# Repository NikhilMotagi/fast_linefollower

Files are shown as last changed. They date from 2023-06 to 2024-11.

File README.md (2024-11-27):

# fast_linefollower
This autonomous robot is designed to accurately follow a defined black line on a white surface. It utilizes an Arduino Nano microcontroller as its brain, processing sensor data and controlling the robot's movement.

**Key Components:**

- **Microcontroller:** Arduino Nano
- **Sensors:** 8-Array IR Sensor
- **Motor Driver:** TB6612FNG
- **Motors:** N20 12V DC Motors
- **Power Supply:** 12V Battery with LM7805 Voltage Regulator

**Operation:**

1. **Sensor Input:** The 8-array IR sensor continuously scans the surface, detecting the contrast between the black line and the white background.
2. **Signal Processing:** The Arduino Nano processes the analog sensor readings, converting them into digital values.
3. **PID Control:** A Proportional-Integral-Derivative (PID) controller is implemented to regulate the robot's speed and steering. The PID algorithm analyzes the error between the desired line position and the actual position, adjusting the motor speeds accordingly.
4. **Motor Control:** The TB6612FNG motor driver receives commands from the Arduino Nano and controls the direction and speed of the two DC motors.

--- 
### Photo Gallery

| PCB Top View  | PCB Bottom View |
| --- | --- |
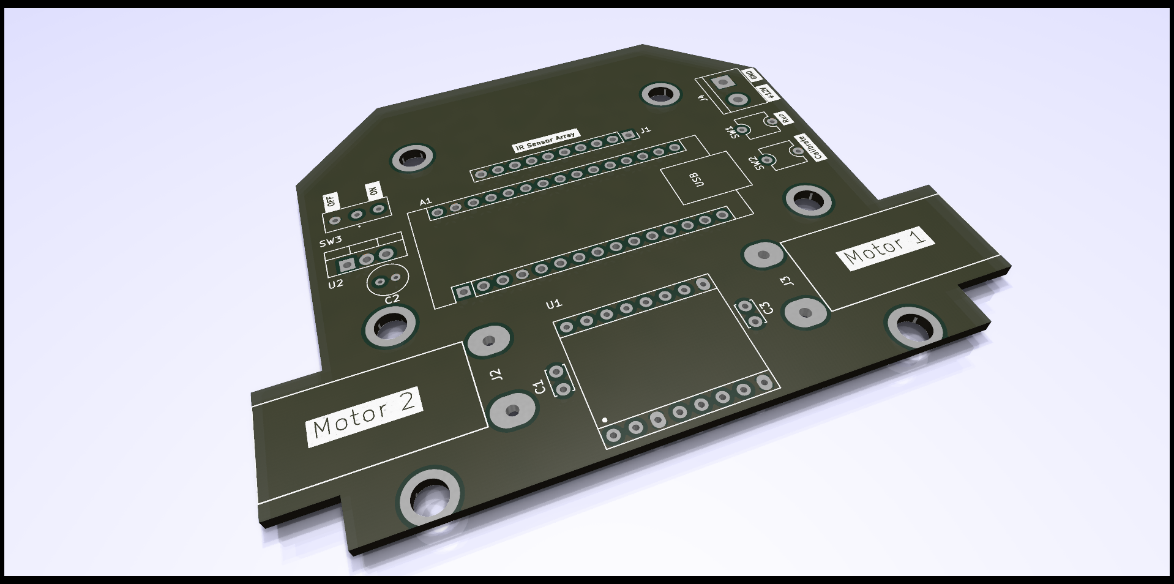
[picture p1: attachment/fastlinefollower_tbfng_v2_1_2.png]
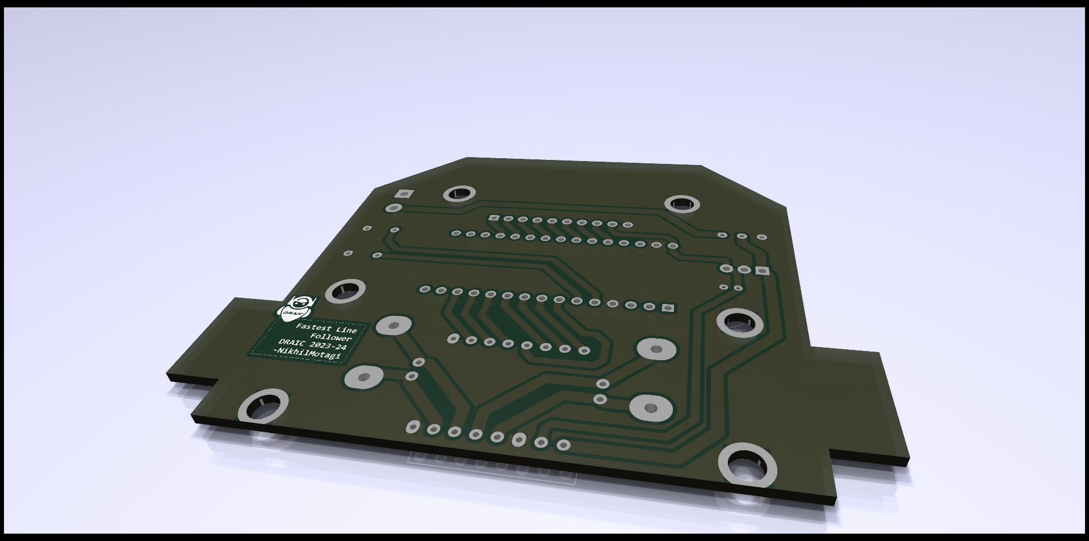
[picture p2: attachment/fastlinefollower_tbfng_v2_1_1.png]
|  |  |

- Assembled render
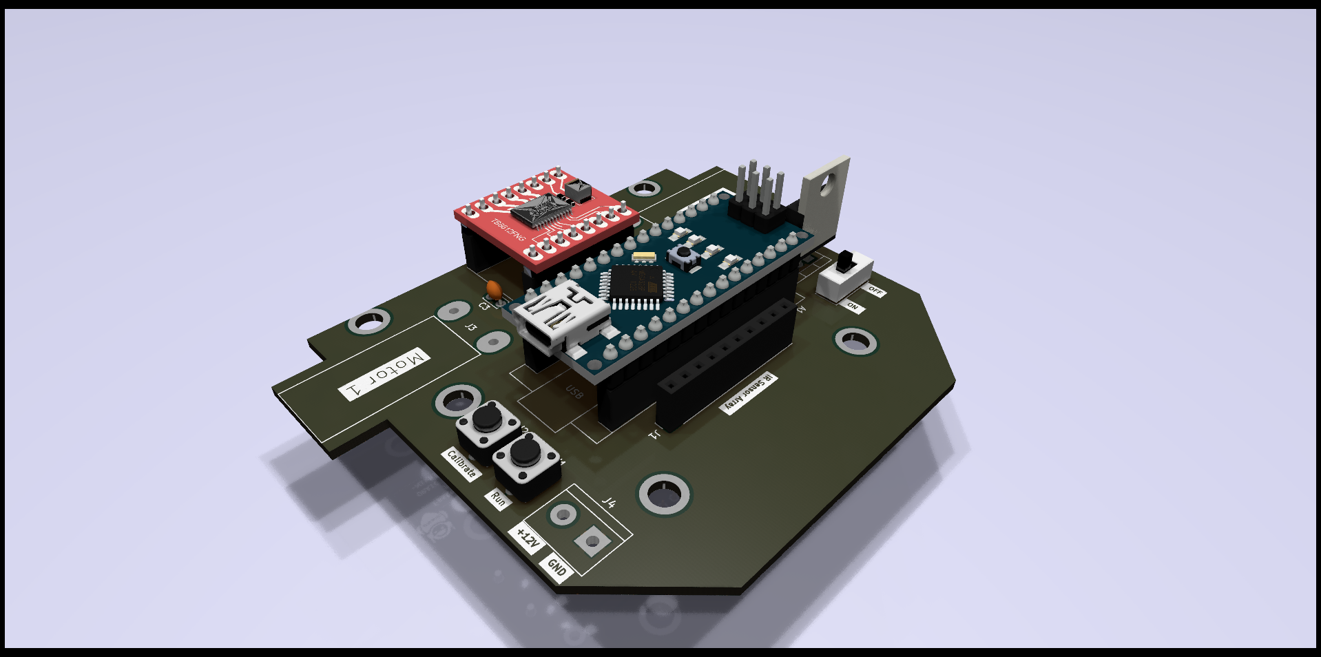
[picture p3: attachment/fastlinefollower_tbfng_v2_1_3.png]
  
- IRL
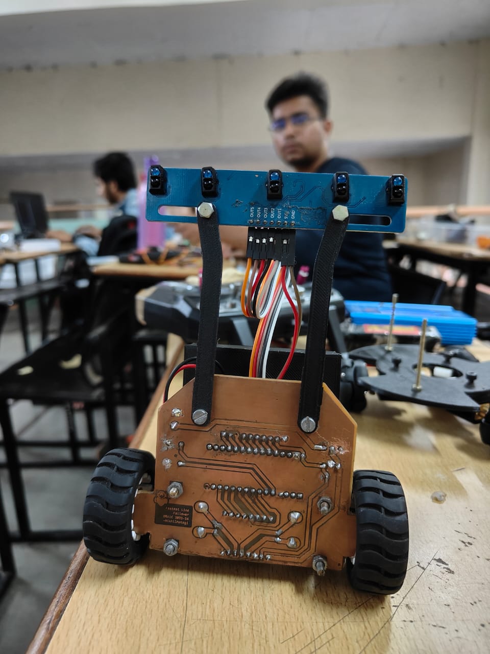
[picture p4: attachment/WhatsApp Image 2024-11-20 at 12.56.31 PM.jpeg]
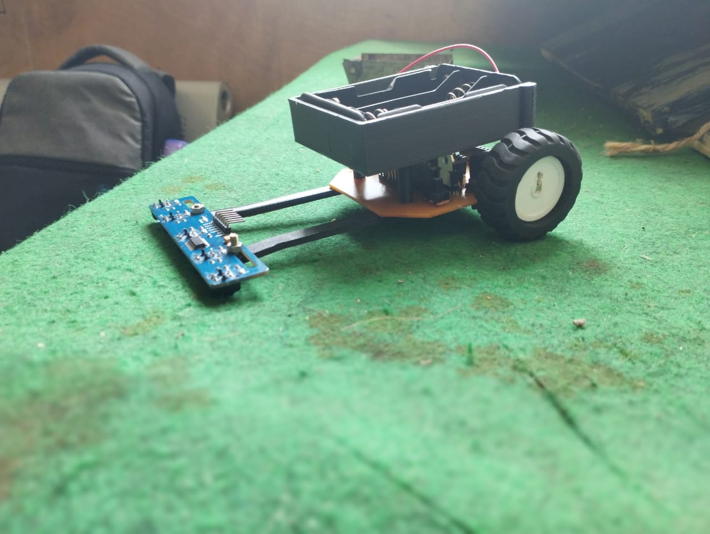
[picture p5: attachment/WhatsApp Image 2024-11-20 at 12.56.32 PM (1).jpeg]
  ||  |
  | ----------| -------------|

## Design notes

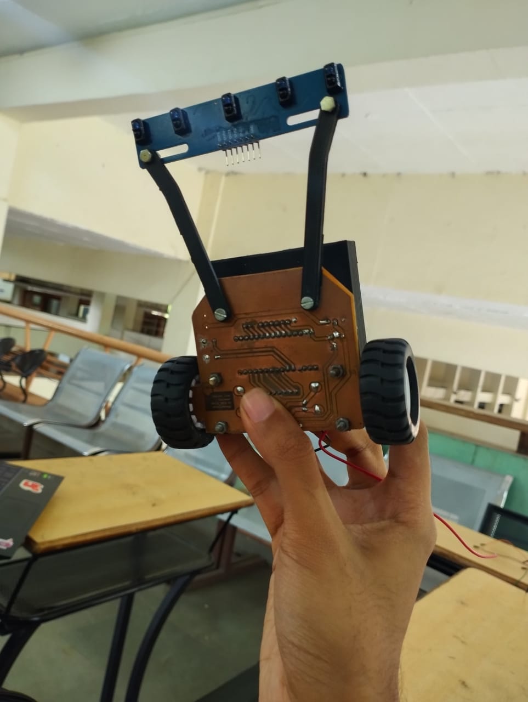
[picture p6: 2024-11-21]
attachment/WhatsApp Image 2024-11-20 at 12.56.32 PM.jpeg

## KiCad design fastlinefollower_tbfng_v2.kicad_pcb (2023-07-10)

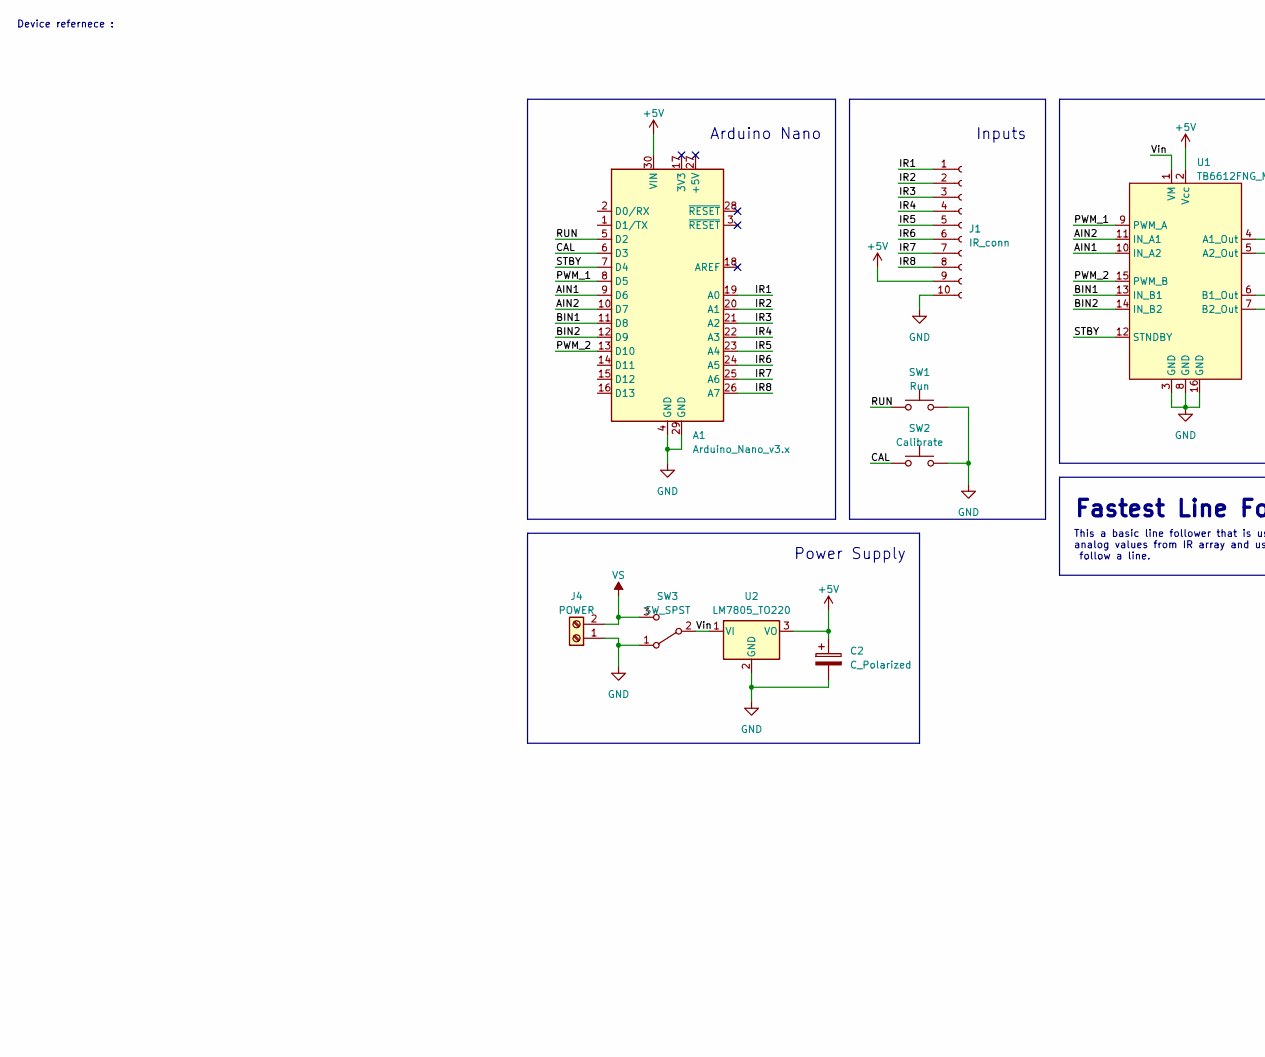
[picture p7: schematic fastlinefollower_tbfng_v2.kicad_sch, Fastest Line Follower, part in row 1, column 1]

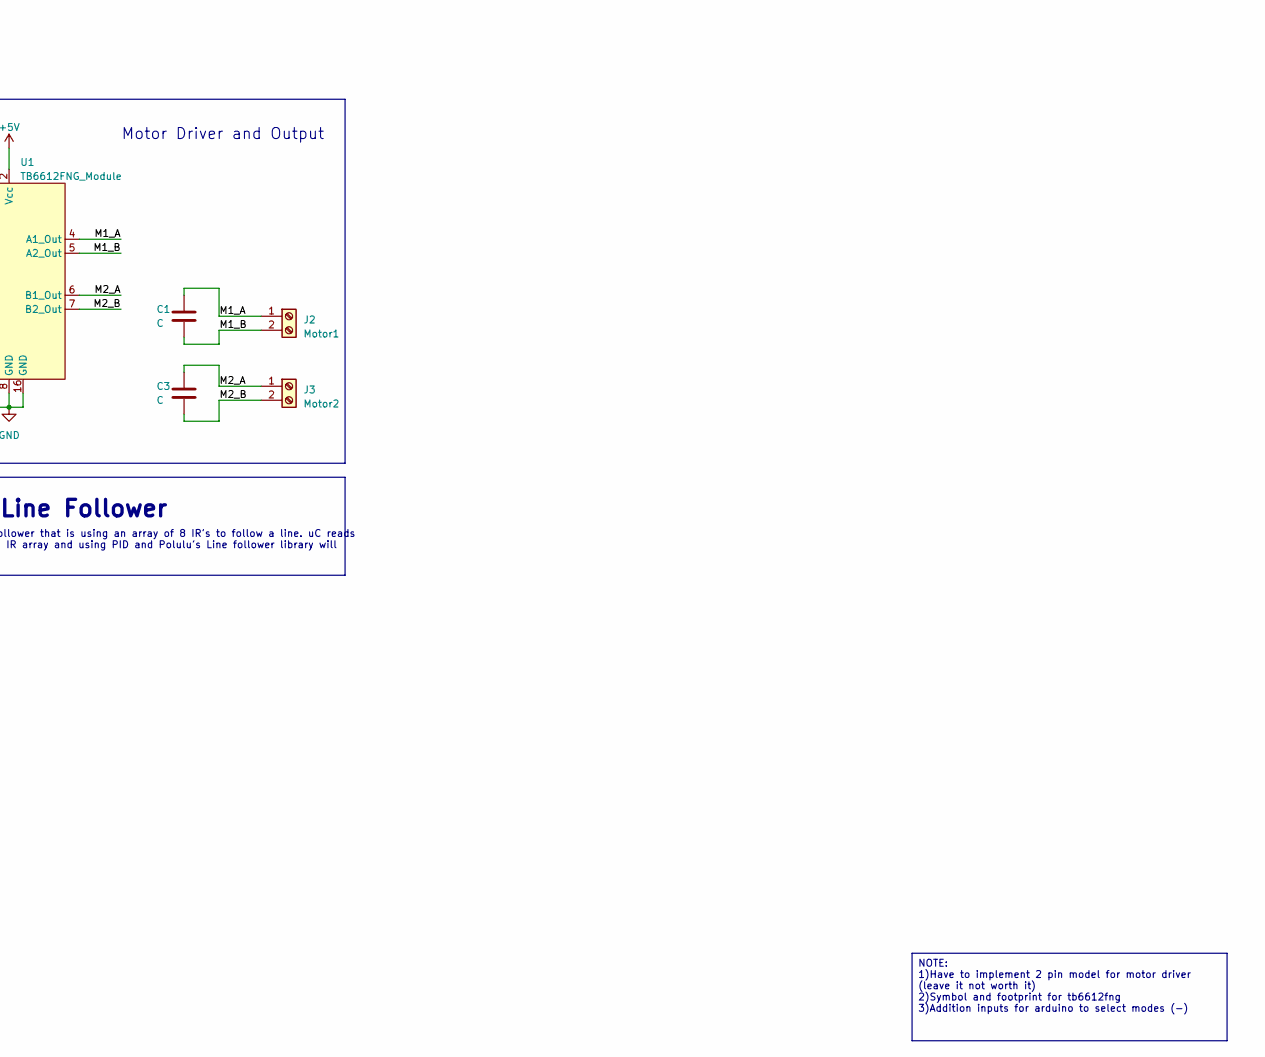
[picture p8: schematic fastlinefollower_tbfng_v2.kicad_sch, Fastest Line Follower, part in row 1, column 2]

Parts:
A1: Arduino_Nano_v3.x; Arduino_Nano
C1, C3: C; C_Disc_D3.4mm_W2.1mm_P2.50mm
C2: C_Polarized; C_Radial_D5.0mm_H7.0mm_P2.00mm
J1: IR_conn; PinSocket_1x10_P2.54mm_Vertical
J2: Motor1; MOTORmount
J3: Motor2; MOTORmount
J4: POWER; TerminalBlock_bornier-2_P5.08mm
SW1: Run; SPST_Pushbutton
SW2: Calibrate; SPST_Pushbutton
SW3: SW_SPST; SPDT_Slidebutton
U1: TB6612FNG_Module; TB1266FNG_Module
U2: LM7805_TO220; TO-220-3_Vertical

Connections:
+5V: A1.30 (VIN), C2.1, J1.9, U1.2 (Vcc), U2.3 (VO)
/AIN1: A1.9 (D6), U1.10 (IN_A2)
/AIN2: A1.10 (D7), U1.11 (IN_A1)
/BIN1: A1.11 (D8), U1.13 (IN_B1)
/BIN2: A1.12 (D9), U1.14 (IN_B2)
/CAL: A1.6 (D3), SW2.1
/IR1: A1.19 (A0), J1.1
/IR2: A1.20 (A1), J1.2
/IR3: A1.21 (A2), J1.3
/IR4: A1.22 (A3), J1.4
/IR5: A1.23 (A4), J1.5
/IR6: A1.24 (A5), J1.6
/IR7: A1.25 (A6), J1.7
/IR8: A1.26 (A7), J1.8
/M1_A: C1.1, J2.1, U1.4 (A1_Out)
/M1_B: C1.2, J2.2, U1.5 (A2_Out)
/M2_A: C3.1, J3.1, U1.6 (B1_Out)
/M2_B: C3.2, J3.2, U1.7 (B2_Out)
/PWM_1: A1.8 (D5), U1.9 (PWM_A)
/PWM_2: A1.13 (D10), U1.15 (PWM_B)
/RUN: A1.5 (D2), SW1.1
/STBY: A1.7 (D4), U1.12 (STNDBY)
/Vin: SW3.2 (B), U1.1 (VM), U2.1 (VI)
GND: A1.4 (GND), A1.29 (GND), C2.2, J1.10, J4.1, SW1.2, SW2.2, SW3.1 (A), U1.3 (GND), U1.8 (GND), U1.16 (GND), U2.2 (GND)
VS: J4.2, SW3.3 (C)

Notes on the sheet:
NOTE: 1)Have to implement 2 pin model for motor driver (leave it not worth it) 2)Symbol and footprint for tb6612fng 3)Addition inputs for arduino to select modes (-)
Device refernece :
Fastest Line Follower
Inputs
Power Supply
Motor Driver and Output
This a basic line follower that is using an array of 8 IR's to follow a line. uC reads analog values from IR array and using PID and Polulu's Line follower library will follow a line.
Arduino Nano

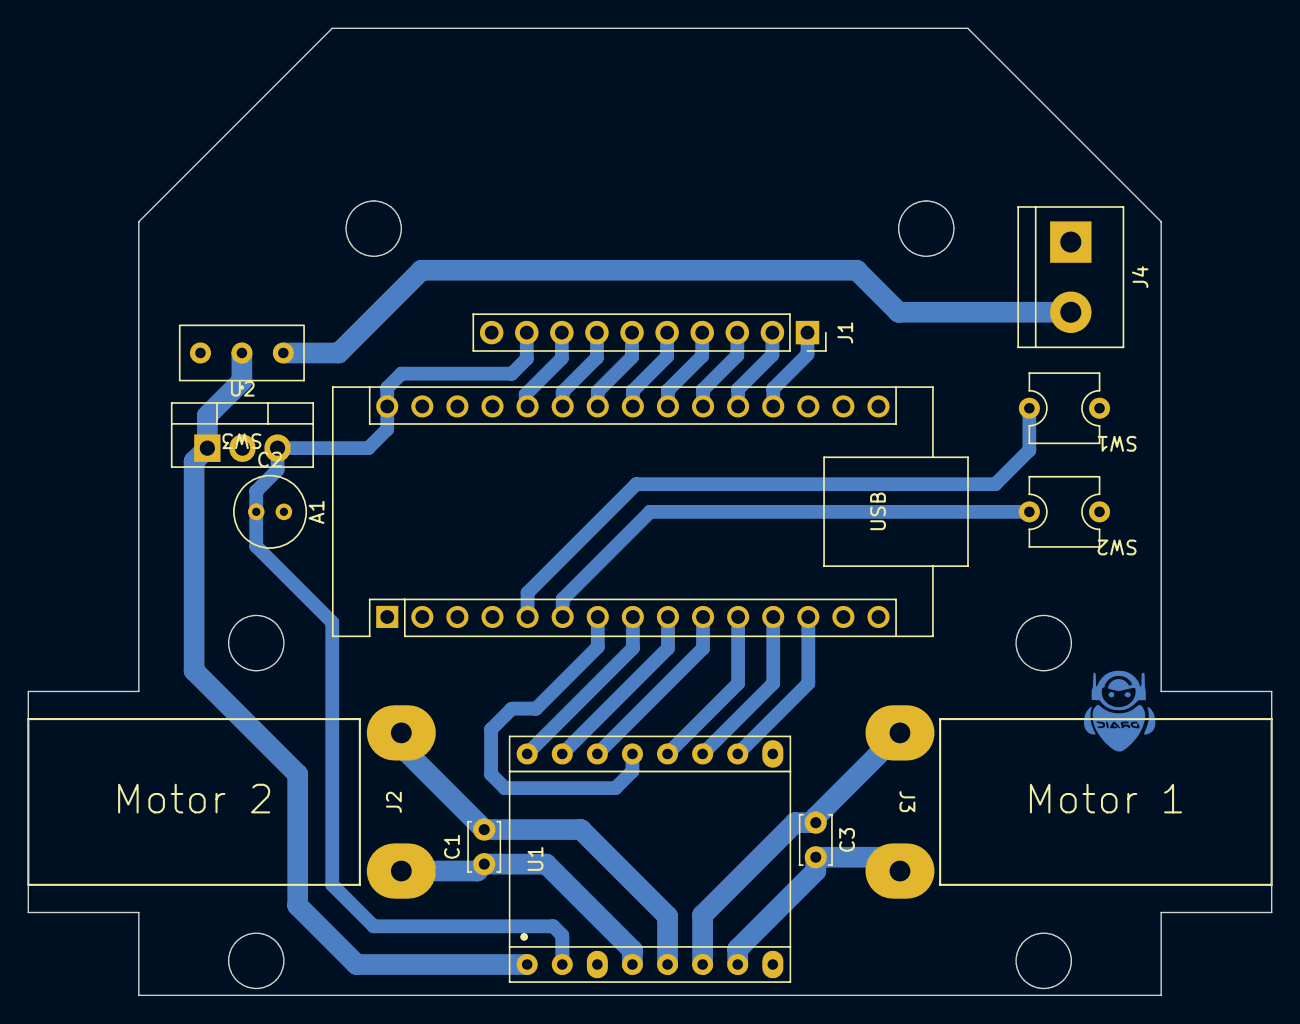
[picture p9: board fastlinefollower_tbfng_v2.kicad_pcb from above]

Board: 2 copper layers, 90.0 x 70.0 mm, 13 parts (0 on the bottom side), 25 nets.

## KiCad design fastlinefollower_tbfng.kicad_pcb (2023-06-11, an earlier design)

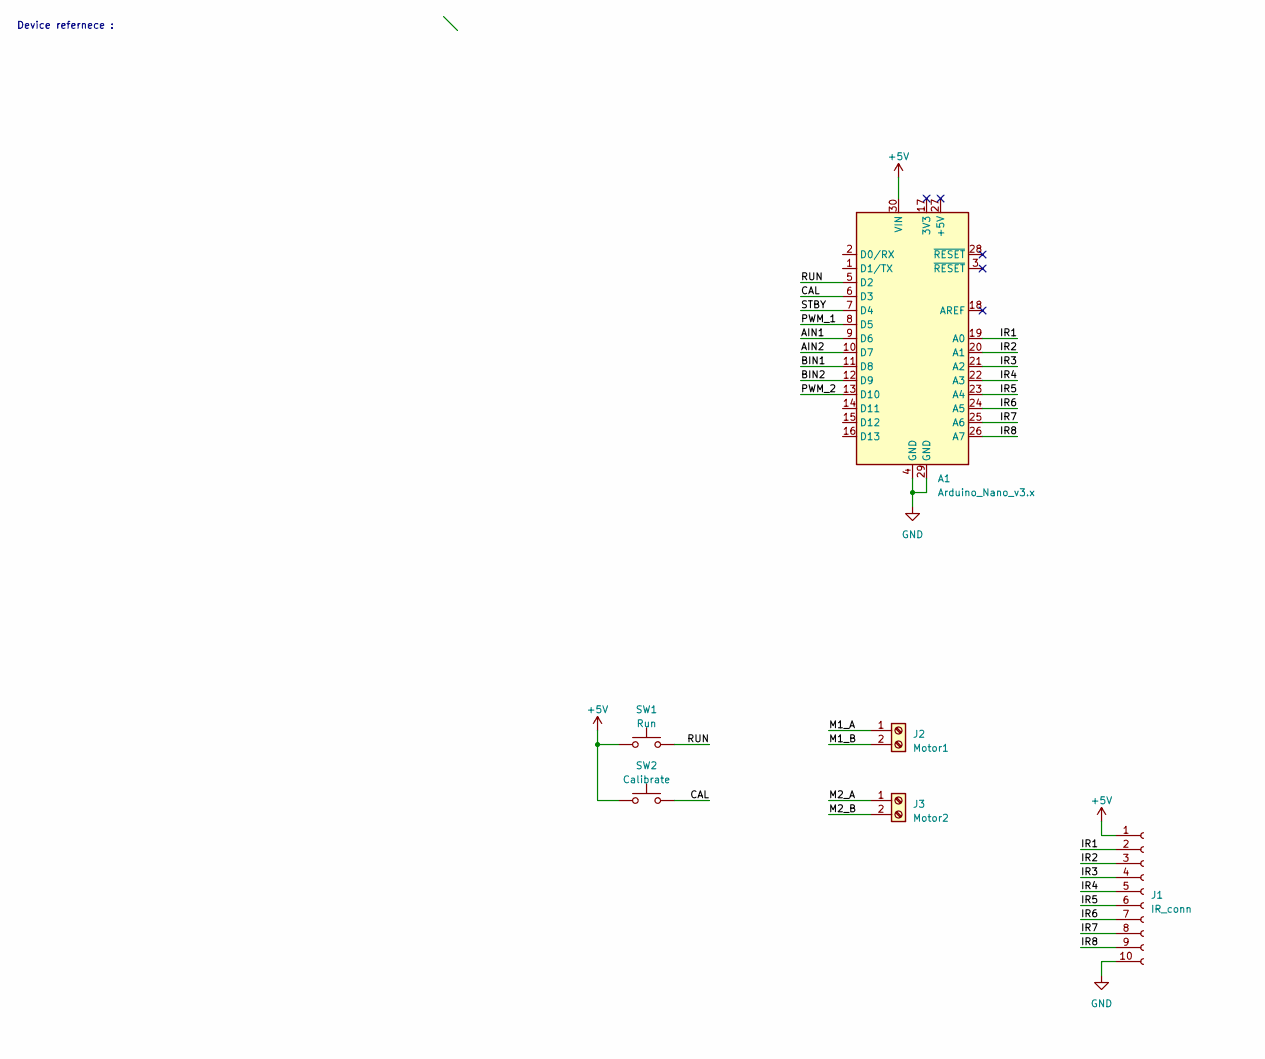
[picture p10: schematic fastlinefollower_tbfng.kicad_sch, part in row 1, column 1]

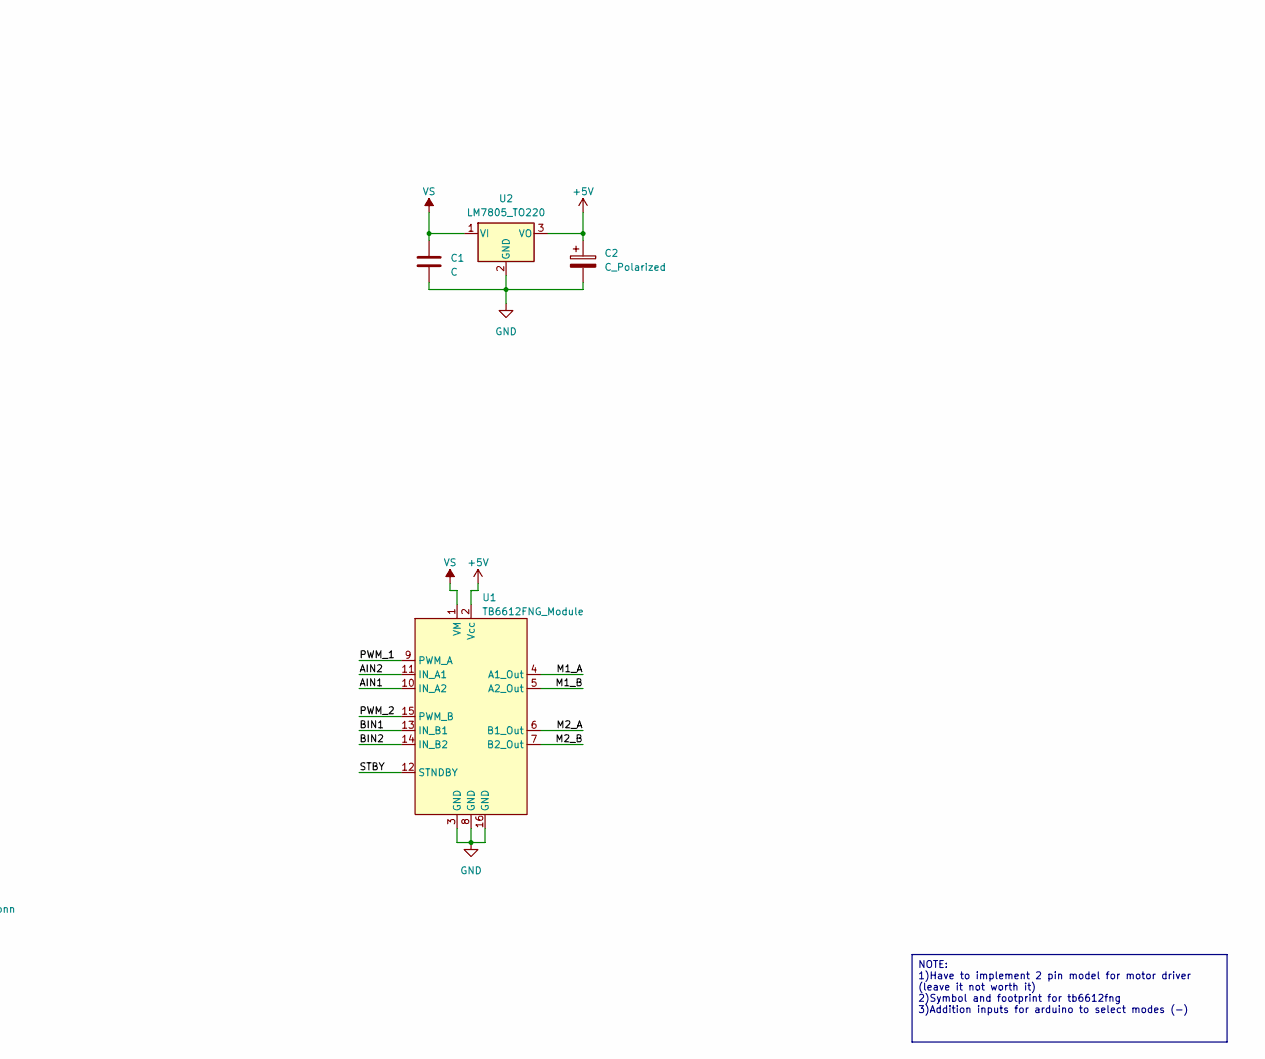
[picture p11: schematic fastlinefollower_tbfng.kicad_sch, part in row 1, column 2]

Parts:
A1: Arduino_Nano_v3.x; Arduino_Nano
C1: C; C_Disc_D5.0mm_W2.5mm_P2.50mm
C2: C_Polarized; C_Radial_D5.0mm_H7.0mm_P2.00mm
J1: IR_conn; PinSocket_1x10_P2.54mm_Vertical
J2: Motor1; TerminalBlock_Altech_AK300-2_P5.00mm
J3: Motor2; TerminalBlock_Altech_AK300-2_P5.00mm
SW1: Run; SW_PUSH_6mm
SW2: Calibrate; SW_PUSH_6mm
U1: TB6612FNG_Module; TB1266FNG_Module
U2: LM7805_TO220; TO-220-3_Vertical

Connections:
+5V: A1.30 (VIN), C2.1, J1.1, SW1.1, SW2.1, U1.2 (Vcc), U2.3 (VO)
/AIN1: A1.9 (D6), U1.10 (IN_A2)
/AIN2: A1.10 (D7), U1.11 (IN_A1)
/BIN1: A1.11 (D8), U1.13 (IN_B1)
/BIN2: A1.12 (D9), U1.14 (IN_B2)
/CAL: A1.6 (D3), SW2.2
/IR1: A1.19 (A0), J1.2
/IR2: A1.20 (A1), J1.3
/IR3: A1.21 (A2), J1.4
/IR4: A1.22 (A3), J1.5
/IR5: A1.23 (A4), J1.6
/IR6: A1.24 (A5), J1.7
/IR7: A1.25 (A6), J1.8
/IR8: A1.26 (A7), J1.9
/M1_A: J2.1, U1.4 (A1_Out)
/M1_B: J2.2, U1.5 (A2_Out)
/M2_A: J3.1, U1.6 (B1_Out)
/M2_B: J3.2, U1.7 (B2_Out)
/PWM_1: A1.8 (D5), U1.9 (PWM_A)
/PWM_2: A1.13 (D10), U1.15 (PWM_B)
/RUN: A1.5 (D2), SW1.2
/STBY: A1.7 (D4), U1.12 (STNDBY)
GND: A1.4 (GND), A1.29 (GND), C1.2, C2.2, J1.10, U1.3 (GND), U1.8 (GND), U1.16 (GND), U2.2 (GND)
VS: C1.1, U1.1 (VM), U2.1 (VI)

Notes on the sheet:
NOTE: 1)Have to implement 2 pin model for motor driver (leave it not worth it) 2)Symbol and footprint for tb6612fng 3)Addition inputs for arduino to select modes (-)
Device refernece :

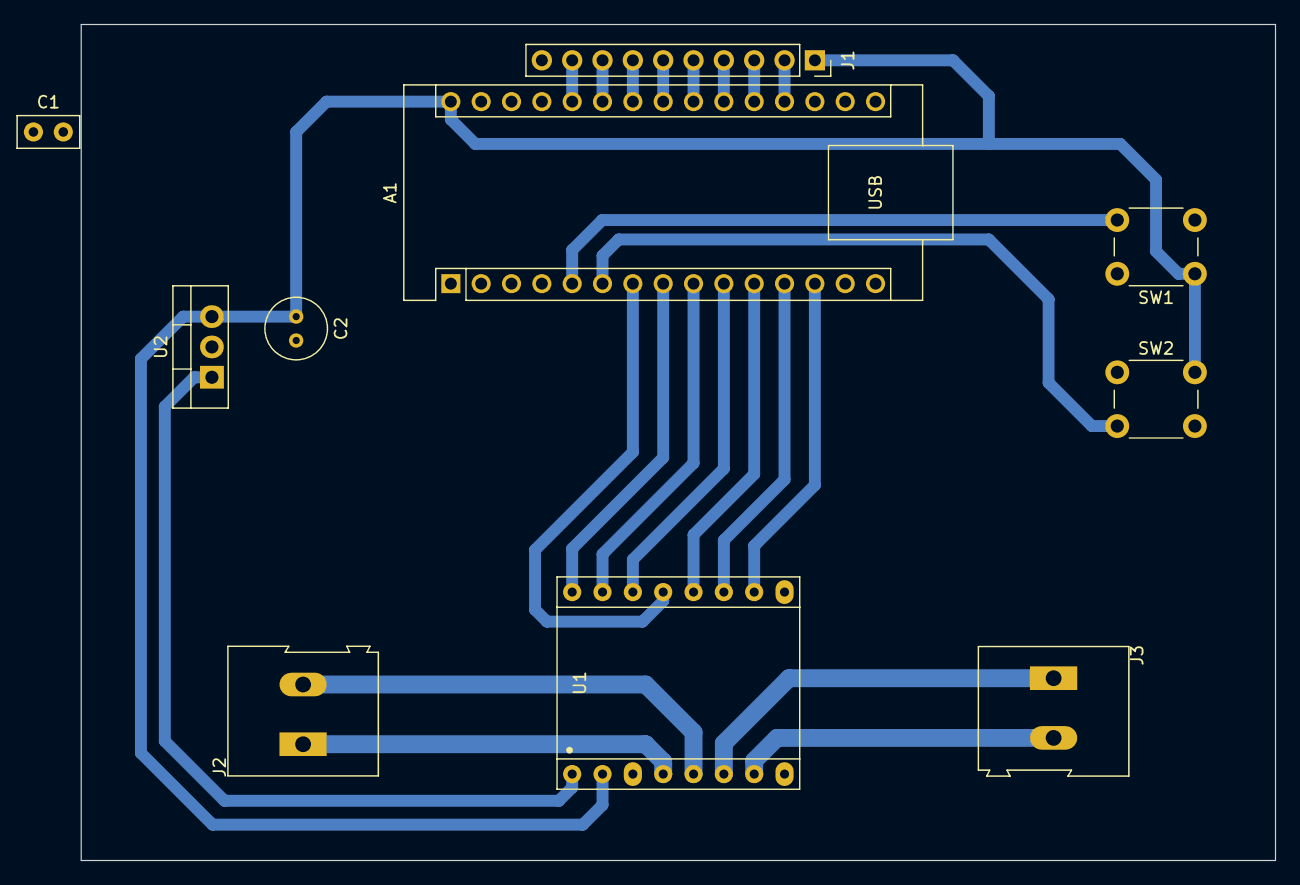
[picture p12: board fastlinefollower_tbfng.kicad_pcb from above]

Board: 2 copper layers, 100.0 x 70.0 mm, 10 parts (0 on the bottom side), 24 nets.

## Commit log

2023-05-23 tbfng looks good
    [fastlinefollower_tbfng.kicad_pcb, fastlinefollower_tbfng.kicad_sch]
2023-05-27 Driver symbol added
    [fastlinefollower_tbfng.kicad_sch]
2023-06-11 basic layout done
    [fastlinefollower_tbfng.kicad_pcb, fastlinefollower_tbfng.kicad_sch]
2023-06-13 well theres a second version now
    [fastlinefollower_tbfng.kicad_sch, fastlinefollower_tbfng_v1.kicad_pcb]
2023-06-27 new layout
    [fastlinefollower_tbfng_v1.kicad_pcb, fastlinefollower_tbfng_v2.kicad_pcb, fastlinefollower_tbfng_v2.kicad_sch]
2023-07-10 final twicks
    [fastlinefollower_tbfng_v2.kicad_pcb, fastlinefollower_tbfng_v2.kicad_sch]
